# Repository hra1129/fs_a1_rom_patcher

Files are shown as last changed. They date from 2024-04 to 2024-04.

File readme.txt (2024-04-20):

MSX2 Panasonic FS-A1 の 1Mbit MaskROM を取り外し、
代わりに 256Kbit EP-ROM を 4つ取り付けるボートです。

MAIN-ROM
SUB-ROM + 16KB-ROM
DESKPACK1
DESKPACK2

この4つに分かれているので、
必要に応じて未装着や別のROMに書き替えるなどして
使うことが出来ます。

KiCad_project/fs-a1_rom_patch_rev3.zip をダウンロードし、
JLCPCB の注文フォームで指定すれば、基板を購入することが
出来ます。

--------------------------------------------------
自己責任でご利用下さい。無保証です。

HRA!

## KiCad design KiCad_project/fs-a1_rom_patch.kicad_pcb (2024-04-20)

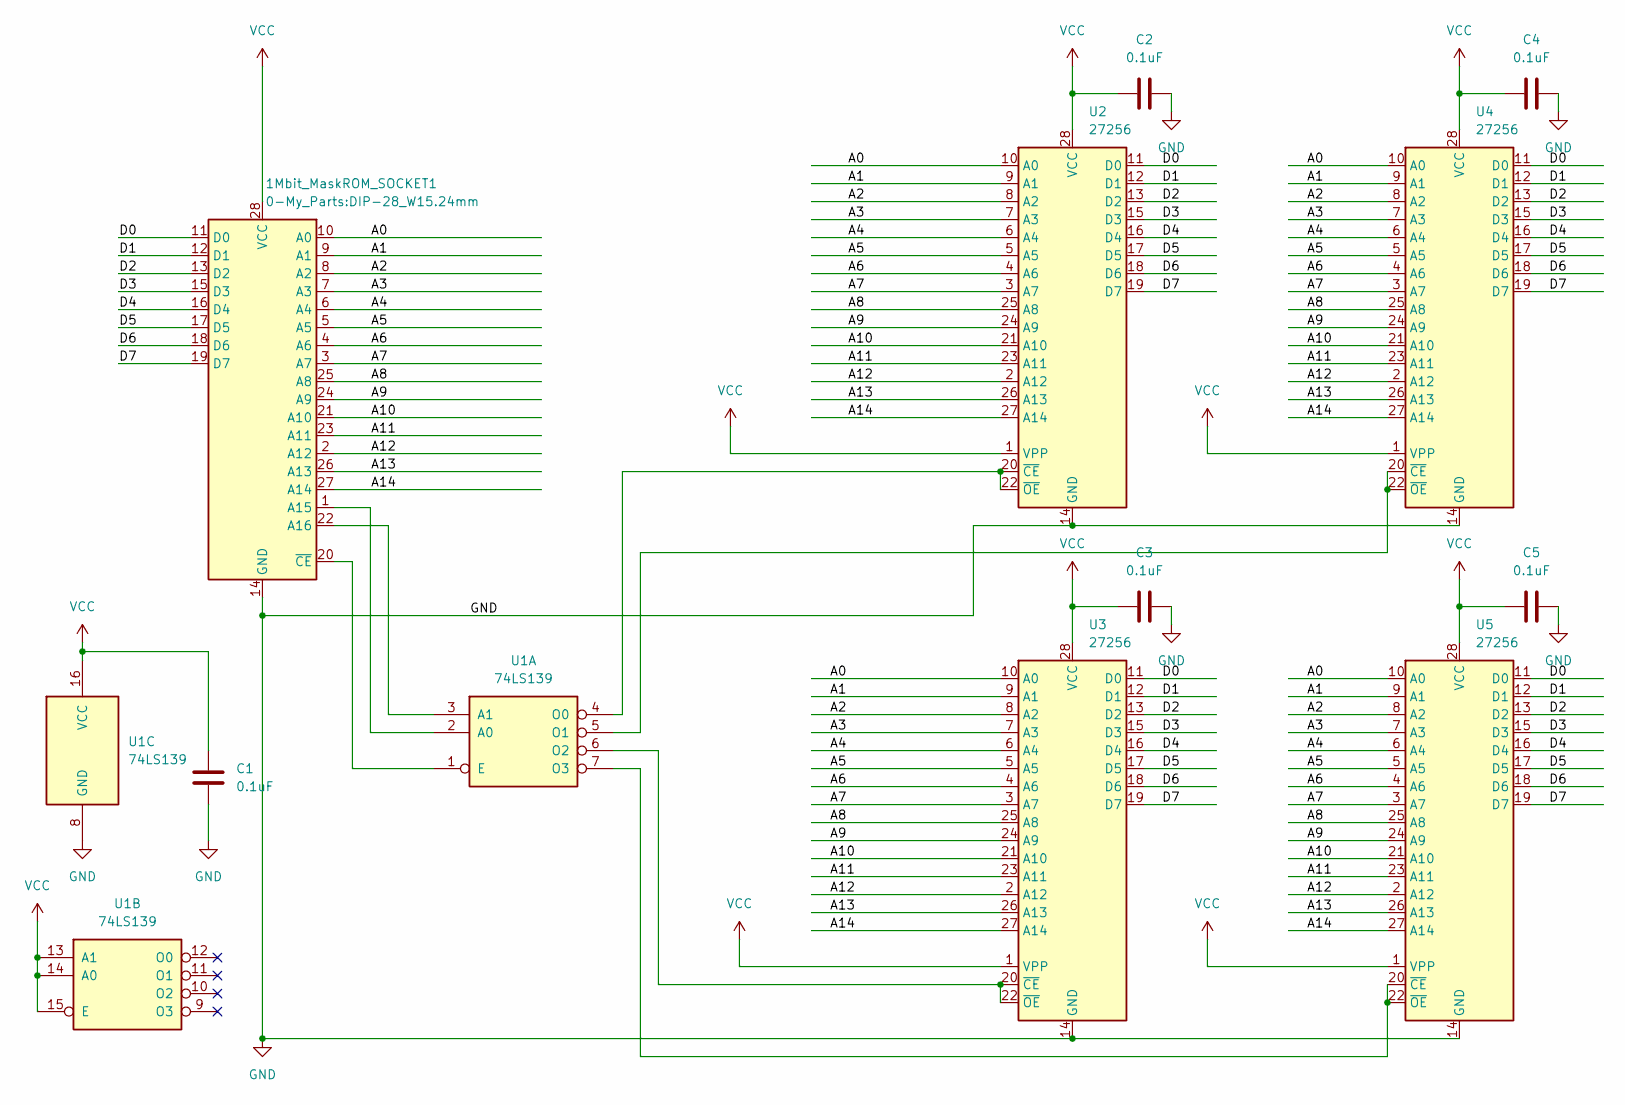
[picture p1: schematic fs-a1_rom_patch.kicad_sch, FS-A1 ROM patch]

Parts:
1Mbit_MaskROM_SOCKET1: DIP-28_W15.24mm
C1, C2, C3, C4, C5: 0.1uF; C_0603_1608Metric_Pad1.08x0.95mm_HandSolder
U1: 74LS139; DIP-16_W7.62mm
U2, U3, U4, U5: 27256; DIP-28_W15.24mm

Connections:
/A0: 1Mbit_MaskROM_SOCKET1.10 (A0), U2.10 (A0), U3.10 (A0), U4.10 (A0), U5.10 (A0)
/A1: 1Mbit_MaskROM_SOCKET1.9 (A1), U2.9 (A1), U3.9 (A1), U4.9 (A1), U5.9 (A1)
/A2: 1Mbit_MaskROM_SOCKET1.8 (A2), U2.8 (A2), U3.8 (A2), U4.8 (A2), U5.8 (A2)
/A3: 1Mbit_MaskROM_SOCKET1.7 (A3), U2.7 (A3), U3.7 (A3), U4.7 (A3), U5.7 (A3)
/A4: 1Mbit_MaskROM_SOCKET1.6 (A4), U2.6 (A4), U3.6 (A4), U4.6 (A4), U5.6 (A4)
/A5: 1Mbit_MaskROM_SOCKET1.5 (A5), U2.5 (A5), U3.5 (A5), U4.5 (A5), U5.5 (A5)
/A6: 1Mbit_MaskROM_SOCKET1.4 (A6), U2.4 (A6), U3.4 (A6), U4.4 (A6), U5.4 (A6)
/A7: 1Mbit_MaskROM_SOCKET1.3 (A7), U2.3 (A7), U3.3 (A7), U4.3 (A7), U5.3 (A7)
/A8: 1Mbit_MaskROM_SOCKET1.25 (A8), U2.25 (A8), U3.25 (A8), U4.25 (A8), U5.25 (A8)
/A9: 1Mbit_MaskROM_SOCKET1.24 (A9), U2.24 (A9), U3.24 (A9), U4.24 (A9), U5.24 (A9)
/A10: 1Mbit_MaskROM_SOCKET1.21 (A10), U2.21 (A10), U3.21 (A10), U4.21 (A10), U5.21 (A10)
/A11: 1Mbit_MaskROM_SOCKET1.23 (A11), U2.23 (A11), U3.23 (A11), U4.23 (A11), U5.23 (A11)
/A12: 1Mbit_MaskROM_SOCKET1.2 (A12), U2.2 (A12), U3.2 (A12), U4.2 (A12), U5.2 (A12)
/A13: 1Mbit_MaskROM_SOCKET1.26 (A13), U2.26 (A13), U3.26 (A13), U4.26 (A13), U5.26 (A13)
/A14: 1Mbit_MaskROM_SOCKET1.27 (A14), U2.27 (A14), U3.27 (A14), U4.27 (A14), U5.27 (A14)
/D0: 1Mbit_MaskROM_SOCKET1.11 (D0), U2.11 (D0), U3.11 (D0), U4.11 (D0), U5.11 (D0)
/D1: 1Mbit_MaskROM_SOCKET1.12 (D1), U2.12 (D1), U3.12 (D1), U4.12 (D1), U5.12 (D1)
/D2: 1Mbit_MaskROM_SOCKET1.13 (D2), U2.13 (D2), U3.13 (D2), U4.13 (D2), U5.13 (D2)
/D3: 1Mbit_MaskROM_SOCKET1.15 (D3), U2.15 (D3), U3.15 (D3), U4.15 (D3), U5.15 (D3)
/D4: 1Mbit_MaskROM_SOCKET1.16 (D4), U2.16 (D4), U3.16 (D4), U4.16 (D4), U5.16 (D4)
/D5: 1Mbit_MaskROM_SOCKET1.17 (D5), U2.17 (D5), U3.17 (D5), U4.17 (D5), U5.17 (D5)
/D6: 1Mbit_MaskROM_SOCKET1.18 (D6), U2.18 (D6), U3.18 (D6), U4.18 (D6), U5.18 (D6)
/D7: 1Mbit_MaskROM_SOCKET1.19 (D7), U2.19 (D7), U3.19 (D7), U4.19 (D7), U5.19 (D7)
GND: 1Mbit_MaskROM_SOCKET1.14 (GND), C1.2, C2.1, C3.1, C4.1, C5.1, U1.8 (GND), U2.14 (GND), U3.14 (GND), U4.14 (GND), U5.14 (GND)
unnamed: 1Mbit_MaskROM_SOCKET1.1 (A15), U1.2 (A0)
unnamed: 1Mbit_MaskROM_SOCKET1.22 (A16), U1.3 (A1)
unnamed: 1Mbit_MaskROM_SOCKET1.20 (~CE), U1.1 (E)
unnamed: U1.4 (O0), U2.20 (~CE), U2.22 (~OE)
unnamed: U1.5 (O1), U4.20 (~CE), U4.22 (~OE)
unnamed: U1.6 (O2), U3.20 (~CE), U3.22 (~OE)
unnamed: U1.7 (O3), U5.20 (~CE), U5.22 (~OE)
VCC: 1Mbit_MaskROM_SOCKET1.28 (VCC), C1.1, C2.2, C3.2, C4.2, C5.2, U1.13 (A1), U1.14 (A0), U1.15 (E), U1.16 (VCC), U2.1 (VPP), U2.28 (VCC), U3.1 (VPP), U3.28 (VCC), U4.1 (VPP), U4.28 (VCC), U5.1 (VPP), U5.28 (VCC)

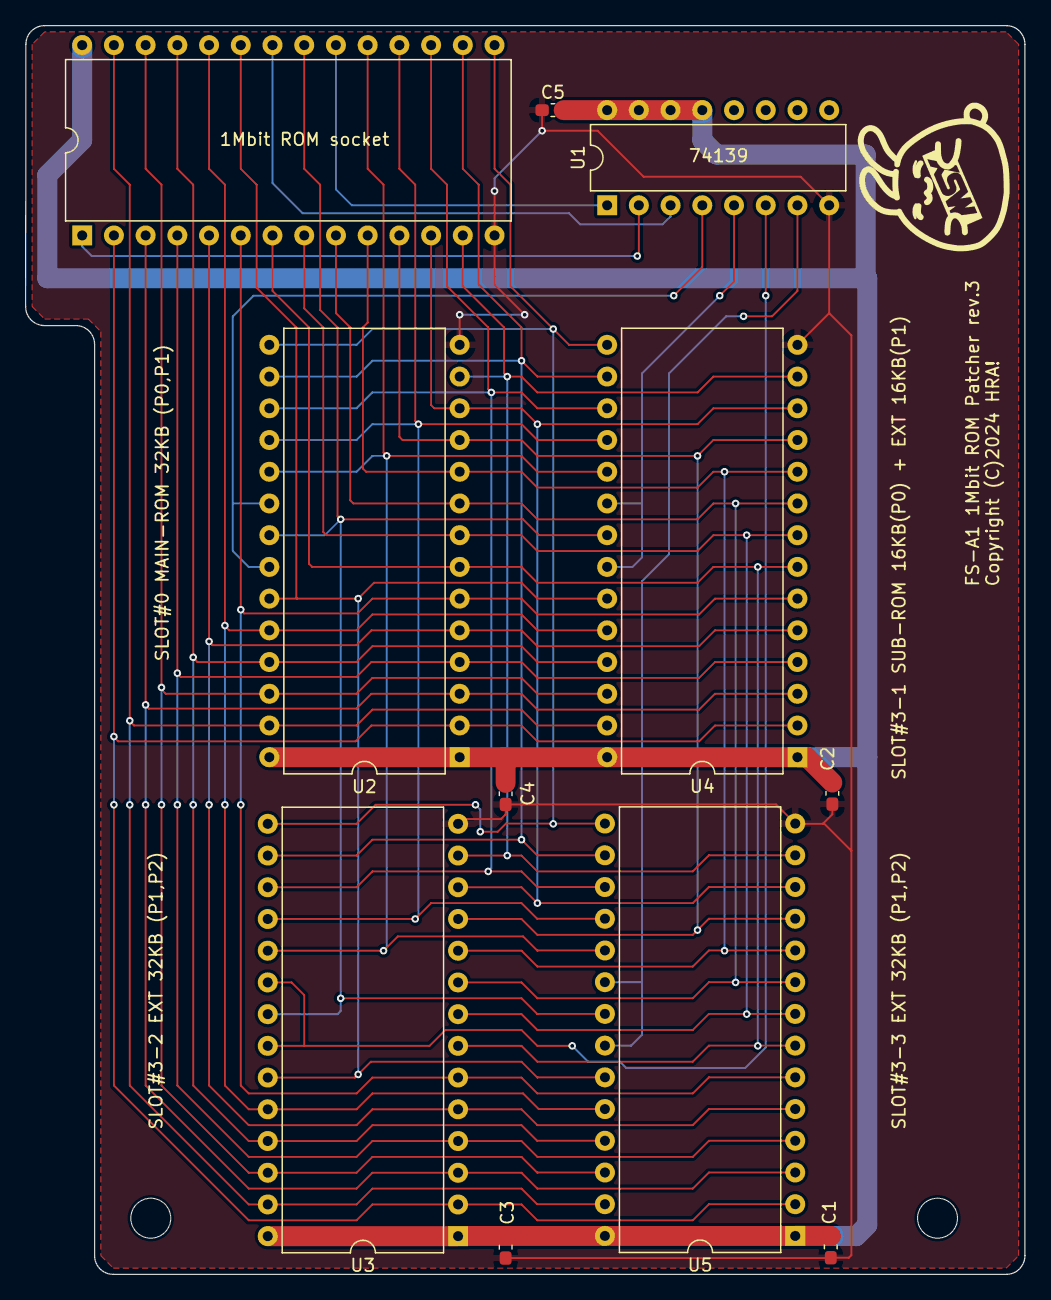
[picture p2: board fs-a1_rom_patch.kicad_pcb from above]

Board: 2 copper layers, 80.0 x 100.0 mm, 13 parts (0 on the bottom side), 32 nets.

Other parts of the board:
MH3, MH4: MountingHole_3.2mm_M3

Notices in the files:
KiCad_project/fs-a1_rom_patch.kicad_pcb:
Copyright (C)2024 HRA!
